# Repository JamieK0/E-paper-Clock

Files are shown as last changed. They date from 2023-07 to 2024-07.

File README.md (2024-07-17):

# Easy on the Eyes E-paper Clock
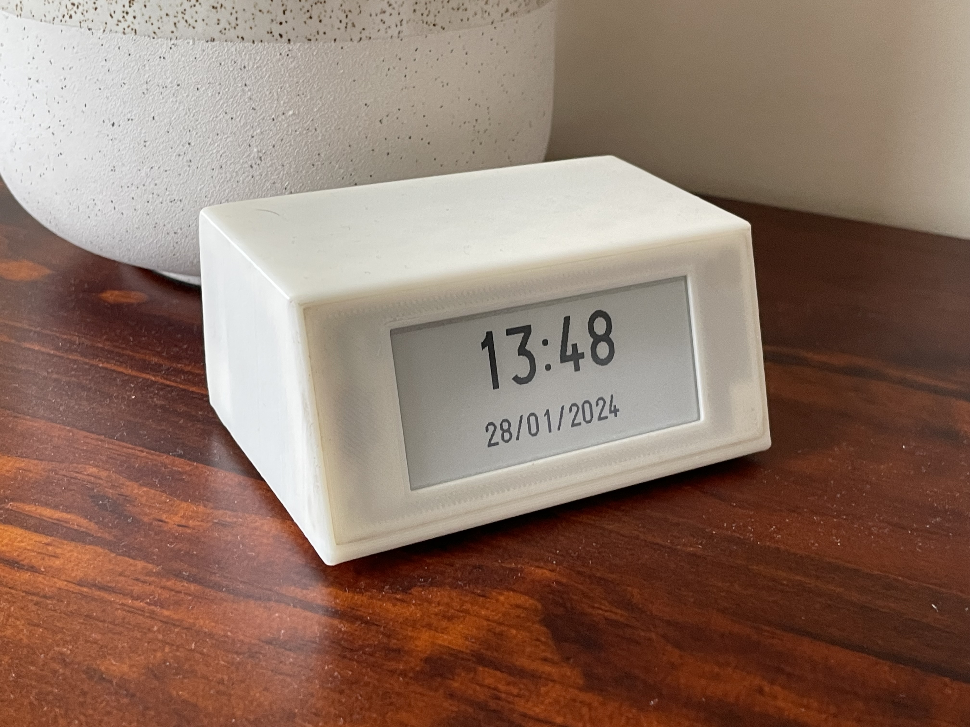
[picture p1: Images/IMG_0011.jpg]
Clock

## Introduction
This project started as a desire to have a modern digital clock that would use the natural light of the room for illumination. This means that the screen is always at a natural brightness, with it looking like paper rather than a traditional screen. By using an E-paper display, blue light is not emitted meaning that the clock does not disrupt your circadian rhythm before bed. It seamlessly updates every minute, and on the hour the screen does a full refresh.

Another useful function of the clock is that it uses a supercapacitor to ensure the time is kept even when it is unplugged for extended periods of time. This means the time does not have to be set again after blackouts like most other clocks. 

## Build Guide
### **Assumed Knowledge**
- Soldering 
- Arduino IDE 
- 3D printing

### **Bill of Materials**
- 1x [Arduino Nano or compatible Nano board](https://core-electronics.com.au/nano-v3-0-board.html)
- 1x [Waveshare 2.9inch E-Paper Module for Raspberry Pi Pico](https://core-electronics.com.au/waveshare-2-9inch-e-paper-module-for-raspberry-pi-pico-296x128-black-white.html) 
- 1x [Makerverse Real Time Clock (RTC) with Supercapacitor Backup RV-3028](https://core-electronics.com.au/catalog/product/view/sku/CE07922)
- 4x [Push Button 12mm x 12mm](https://core-electronics.com.au/tactile-switch-buttons-12mm-square-6mm-tall-x-10-pack.html)
- 1x [Micro USB Cable](https://core-electronics.com.au/usb-cable-type-a-to-micro-b-1m.html)
- 6x M3 4mm length (OD 4.5mm) heated inserts
- 3x M3 16mm hex socket grubscrews
- Jumper wires
- Wires 
- Solder
- White PLA 3D printer filament\

### **Tools**
- 3D printer 
- Soldering Iron
- Hot glue gun

### **Wiring Table**

| Arduino | E-paper Display | RTC unit | Buttons |
| --- | --- | --- | --- |
| 5V | VSYS | | |
| 3V3 | | Vcc | |
| GND | GND | GND | All buttons bottom right pin |
| A4 | | SDA | |
| A5 | | SCL | |
| D2 | | INT | |
| D3 | | | Button 1 bottom left pin (Down) |
| D4 | | | Button 2 bottom left pin (Change function from changing hours to changing minutes to exit changing time mode) |
| D5 | | | Button 3 bottom left pin (Turn on changing time mode) |
| D6 | DC | | |
| D7 | BUSY | | |
| D8 | | | Button 4 bottom right pin (Up) |
| D9 | RST | | |
| D10 | CS | | |
| D11 | DIN | | |
| D13 | CLK | CLK | |

### **Schematic**
Schematic
### **Assembly Instructions**
1. Connect the jumper wires from the Arduino’s male headers to the female headers on the E-paper module according to the schematic diagram or wiring table below. Some connections may need to be soldered, like the D13-CLK-CLK connection, since multiple devices are connecting to the same pin on the Arduino. The buttons all have to be soldered as well. Keep at least 8cm on each wire connected to the button so that there is enough slack for the buttons to be placed at the back of the case.
2. Optionally hot glue the jumper wire connections so that they cannot lose contact over time. For a more permanent setup, all the connections can be soldered.
3. Plug the Arduino Nano into your computer and adjust the Arduino sketch.
   	1. Ensure that the ZIP libraries are all installed. They are all on the Github repository below under the E-paper_Clock folder. Install them at Sketch → Include Library → Add .ZIP Library. The libraries are Low Power, GxEPD2 and U8g2 for Adafruit GFX.
	2. Ensure that the time and date variables (int year =, int month =, etc) are set to the current date and time.Variables
	3. Uncomment line 59 by removing the ‘//’ from the start. Line 59:
```
//rtc.setTime(sec, minute, hour, day, date, month, year); //USE THIS TO INITALLY SET TIME. Once set it needs to be commented out so that it doesn't get set to this time every restart
```
3.
   	4. Upload the sketch. Set the board to Arduino AVR Boards → Arduino Nano. 
	5. Turn the line above back into a comment by adding the ‘//’ to the start so that it looks like:
```
//rtc.setTime(sec, minute, hour, day, date, month, year); //USE THIS TO INITALLY SET TIME. Once set it needs to be commented out so that it doesn't get set to this time every restart
```
3.
	6. Upload the sketch again. The clock is now programmed.
4. 3D print the 3 case parts. They can be printed individually or all together.
5. The main case might need a brim depending on your printer since the contact area is quite small.

#### Print settings:
- Filament type: PLA
- Nozzle Temperature: 210ºC
- Bed Temperature: 60ºC
- Infill: 15%
- Layer Height: 0.2mm
- Perimeters: 3
- Solid Layers:
- Top: 4
- Bottom: 4
Print
6. Melt the heated inserts into the 6 holes in the 3d print using a soldering iron. [Video demonstration](https://youtu.be/i6GkWjcWj5w?t=235).
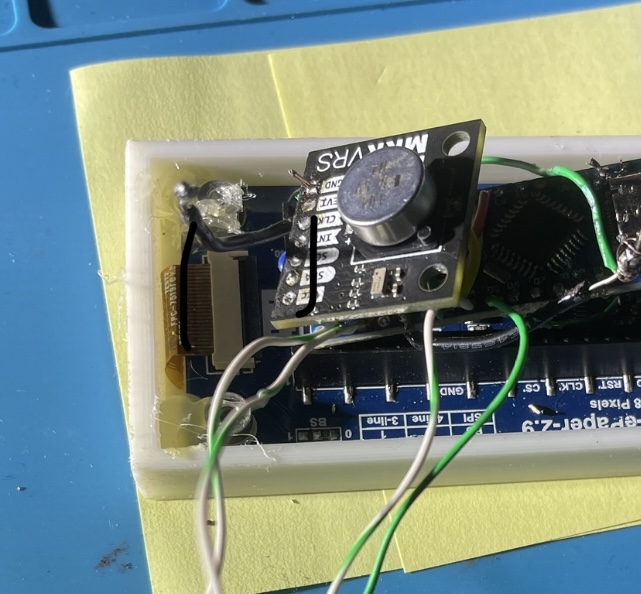
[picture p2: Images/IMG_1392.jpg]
Build
7. Remove the e-paper screen protector and position the screen in the 3d print with the screen opening. Hot glue the corners of the back of the screen to the 3d print.
8. Move all the electronics through the front of the main case and press the front closed. Its friction fit so it might take some force depending on your printer’s dimensional accuracy.
9. Hot glue each button to the back piece in the button holes. Order the buttons so that they make sense when using them to change the time, i.e. the down button is below the up button.
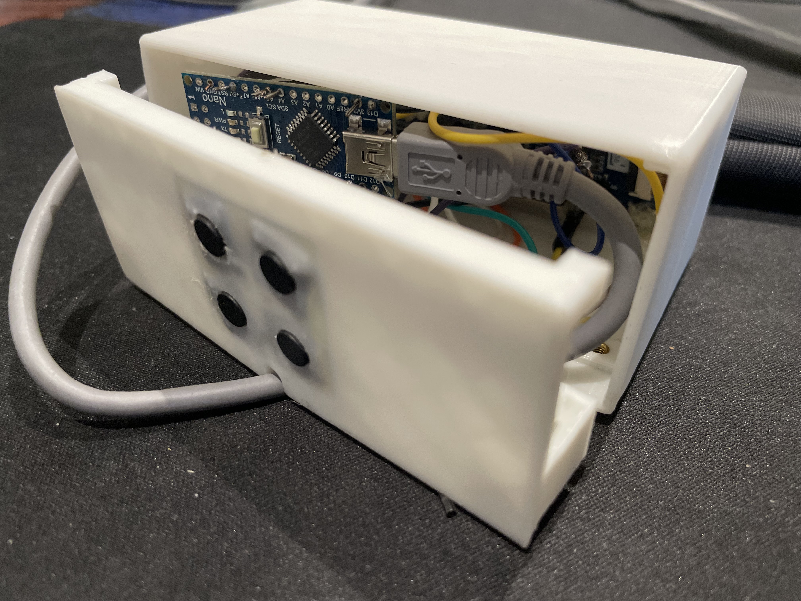
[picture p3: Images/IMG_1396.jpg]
Build2
10. Plug the USB cable into the Arduino and guide the cable through the hole at the bottom of the back piece.
11. Push the back piece into the case of the clock. Once again it’s a friction fit.
12. Screw the 3 grubscrews through the heated inserts at the bottom of the case. This will hold all the pieces of the case together.
13. Plug the Arduino to a USB wall plug or computer port for power.

## How to Adjust the Time
1. Click the ‘Changing time mode button’
2. Use the up and down button to change the hour. There might be a little delay since e-paper screens have a low refresh rate.
3. Click the change function button so that the up and down buttons can be used to adjust the minutes.
4. Click the change function button again to exit change time mode. Once the screen does a full refresh, the new time is saved.

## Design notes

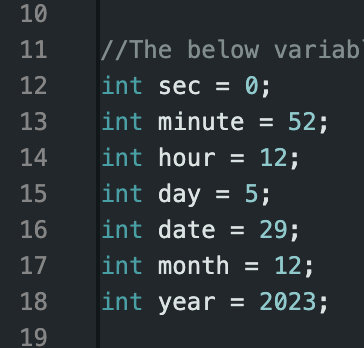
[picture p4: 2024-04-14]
Images/Screenshot 2024-04-13 at 2.12.42 pm.png

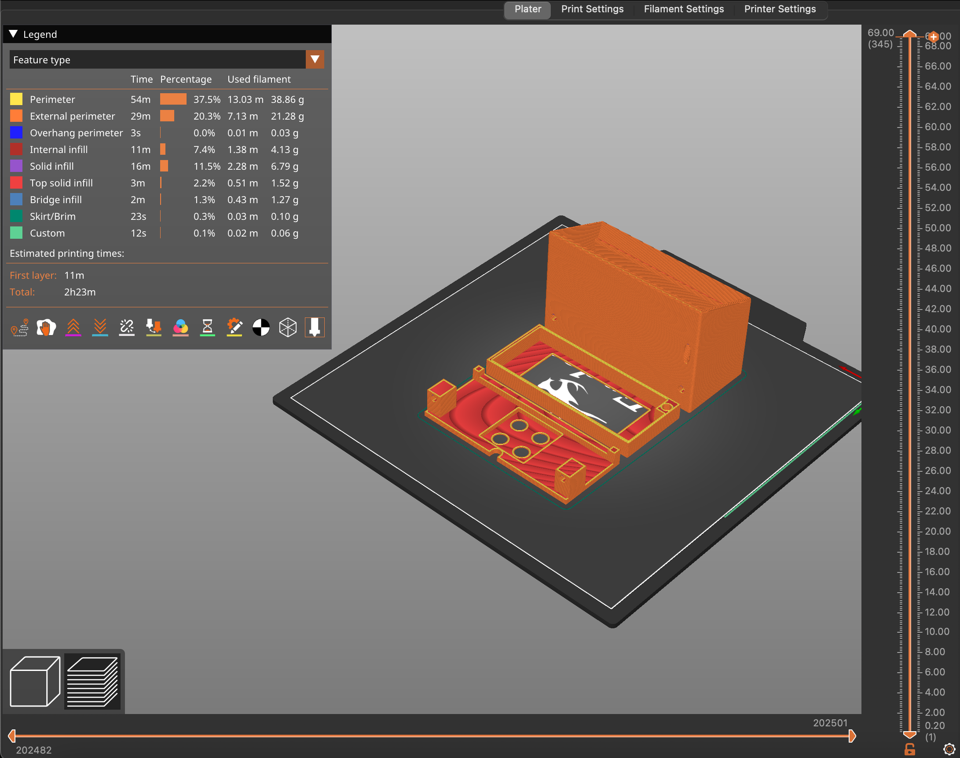
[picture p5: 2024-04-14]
Images/Screenshot 2024-04-13 at 2.23.16 pm.png

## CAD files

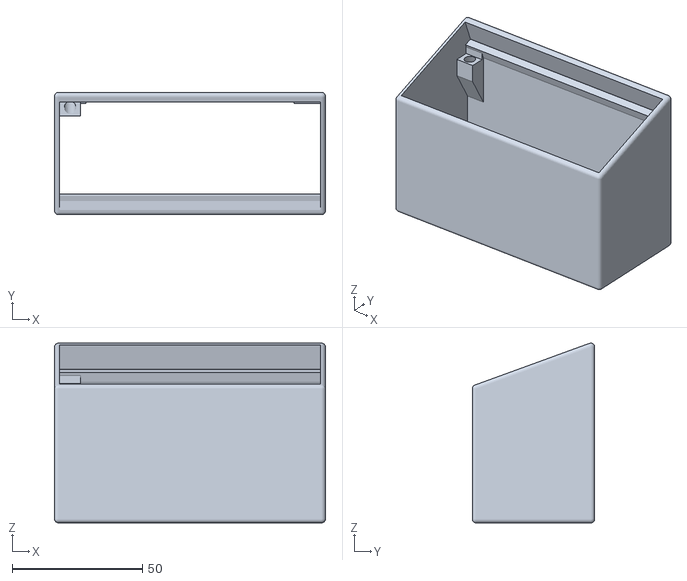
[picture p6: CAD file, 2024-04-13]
3D Models/Case.stl
104.0 x 47.0 x 69.0

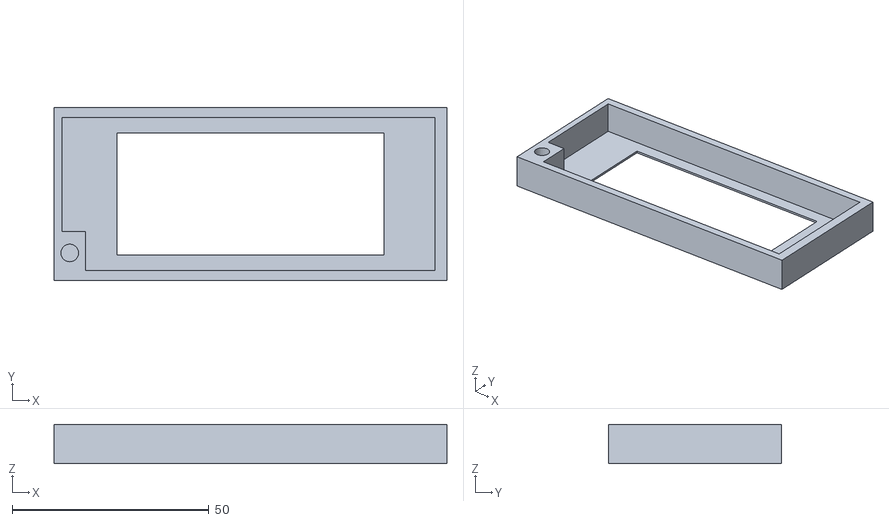
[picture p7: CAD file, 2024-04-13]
3D Models/Front.stl
100.0 x 44.0 x 10.0

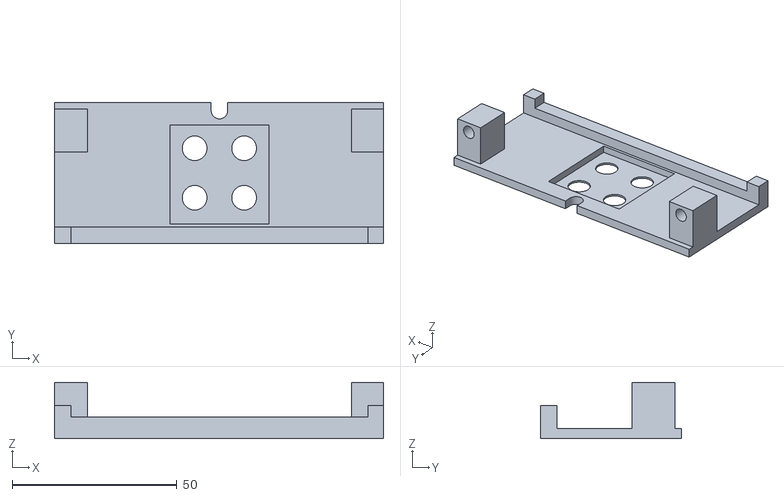
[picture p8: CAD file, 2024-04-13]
3D Models/Back.stl
99.8 x 42.8 x 17.0

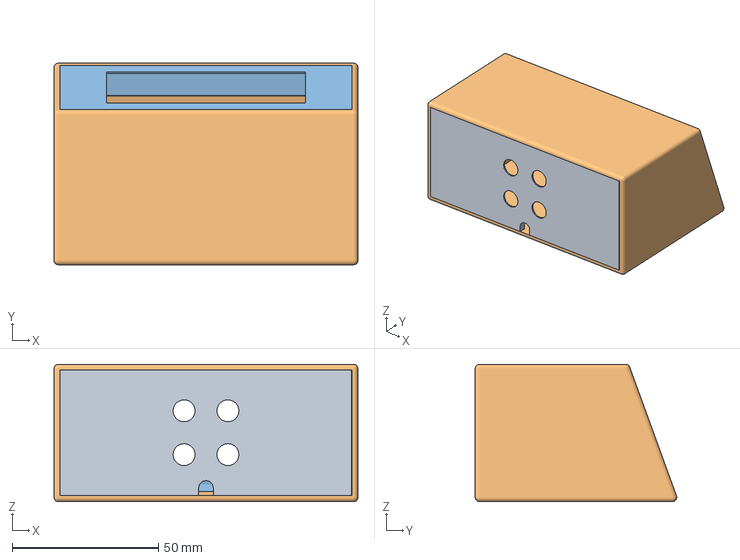
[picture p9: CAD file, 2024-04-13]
3D Models/Combined.3mf
104.0 x 69.0 x 47.0 mm

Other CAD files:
3D Models/Project File Fusion 360.f3d

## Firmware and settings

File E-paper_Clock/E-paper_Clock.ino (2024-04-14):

#include <RV-3028-C7.h>             // RTC Library
#include <LowPower.h>               // Reduces power consumption https://github.com/rocketscream/Low-Power
#include <U8g2_for_Adafruit_GFX.h>  // https://github.com/olikraus/U8g2_for_Adafruit_GFX
#include <GxEPD2_BW.h>              // including both doesn't use more code or ram

// select the display class and display driver class in the following file (new style):
#include "GxEPD2_display_selection.h"

//The below variables control what the date will be set to. Uncomment the line bellow in setup that sets the rtc to the time here. After compiling, the line needs to be commented out again so that the Arduino does not set the time to this time every time it loses power
int sec = 0;
int minute = 52;
int hour = 12;
int day = 5;
int date = 29;
int month = 12;
int year = 2023;

U8G2_FOR_ADAFRUIT_GFX u8g2Fonts;  // font constructor
RV3028 rtc;                       // create the RTC object

const uint8_t wakeUpPin(2);  // connect Arduino pin D2 to RTC's SQW pin. Wakes up the Arduino each minute from sleep mode.

const uint8_t changeFunc(4);  // Button to change function from changing hours to changing minutes to exit changing time mode
const uint8_t changeOn(5);    // Button to turn on changing time mode, this button causes the interrupt. Do not change this pin to any other pin unless the PCINT paramaters are also changed below.
const uint8_t up(8);          // Button to increase time
const uint8_t down(3);        // Button to decrease time

volatile int changeTime = 0; //Integer that gets changed when the interrupt occurs
int changeFuncState = 0;  //Function button set to 0 initally

void setup() {
  Serial.begin(115200);
  Wire.begin();
  if (rtc.begin() == false) {
    Serial.println("Something went wrong, check wiring");
    while (1)
      return;
  } else
    Serial.println("RTC online!");
  Serial.println();

  u8g2Fonts.begin(display);  // connect the u8g2 display

  // configures interupt pin
  pinMode(wakeUpPin, INPUT_PULLUP);

  // time adjustment buttons with pullup resistor
  pinMode(changeOn, INPUT_PULLUP);
  pinMode(changeFunc, INPUT_PULLUP);
  pinMode(up, INPUT_PULLUP);
  pinMode(down, INPUT_PULLUP);

  // allows for the change time buttons to interput the loop
  PCICR |= B00000100;                                      //turns on PCINT for pins in group D
  PCMSK2 |= B00100000;                                     //Pin D5 will cause interupt
  rtc.enableTrickleCharge(TCR_3K);                         //series resistor 3kOhm
  //rtc.setTime(sec, minute, hour, day, date, month, year);  //USE THIS TO INITALLY SET TIME. Once set it needs to be commented out so that it doesn't get set to this time every restart
  displayDate();
}

ISR(PCINT2_vect) {
  changeTime = 1;
}


// Displays the date in the bottom half of the screen
// and does a complete screen refresh
void displayDate() {
  Serial.println("DISPLAY DATE = start");

  display.init();

  display.setRotation(3);  //0 is 'portrait'

  u8g2Fonts.setForegroundColor(GxEPD_BLACK);
  u8g2Fonts.setBackgroundColor(GxEPD_WHITE);
  u8g2Fonts.setFont(u8g2_font_logisoso20_tr);

  rtc.updateTime();

  String dateString = rtc.stringDate();  //rtc to output current date
  Serial.println(rtc.stringDate());

  uint16_t x = 73;
  uint16_t y = 110;  //bottom
  // covers bottom half
  display.setFullWindow();
  display.firstPage();
  do  // update the whole screen
  {
    u8g2Fonts.setCursor(x, y);
    u8g2Fonts.print(rtc.stringDate());
  } while (display.nextPage());
  display.hibernate();
  Serial.println("DISPLAY DATE = finished");
}

// Displays the time in the top half of the screen, as a partial refresh
void displayTime() {
  Serial.println("DISPLAY TIME = start");
  rtc.updateTime();

  u8g2Fonts.setForegroundColor(GxEPD_BLACK);
  u8g2Fonts.setBackgroundColor(GxEPD_WHITE);
  // Only numbers and symbols to save space.https://github.com/olikraus/u8g2/wiki/fntlist99#50-pixel-height
  u8g2Fonts.setFont(u8g2_font_logisoso50_tn);

  uint16_t x = 70;
  uint16_t y = 62;  //top half, depends on font

  display.setPartialWindow(0, 0, display.width(), display.height() / 2);
  display.firstPage();
  do  // Update the upper part of the screen
  {
    u8g2Fonts.setCursor(x, y);
    if (rtc.getHours() < 10) {
      u8g2Fonts.print(0);
      u8g2Fonts.print(rtc.getHours());
    } else {
      u8g2Fonts.print(rtc.getHours());
    }
    u8g2Fonts.print(":");
    if (rtc.getMinutes() < 10) {
      u8g2Fonts.print(0);
      u8g2Fonts.print(rtc.getMinutes());
    } else {
      u8g2Fonts.print(rtc.getMinutes());
    }
  } while (display.nextPage());
  display.hibernate();
  Serial.println("DISPLAY TIME = finish");
}


void loop() {
  Serial.println("LOOP = start");

  if (rtc.getMinutes() == 0) {
    // Refresh the display completely on the hour
    displayDate();
  }

  displayTime();

  Serial.println("LOOP = before sleep");

  delay(500);

  rtc.enablePeriodicUpdateInterrupt(0, 0);

  // Allow wake up pin to trigger on interrupt low.
  attachInterrupt(digitalPinToInterrupt(2), alarmIsr, FALLING);

  Serial.println("VOID LOOP = powering down");

  delay(500);  // if this isn't here the arduino seems to fall asleep before finishing the last line

  // Power down
  LowPower.powerDown(SLEEP_FOREVER, ADC_OFF, BOD_OFF);

  // Wakes up here!
  Serial.println("VOID LOOP = woke up");

  // Disable external pin interrupt on wake up pin.
  detachInterrupt(digitalPinToInterrupt(2));

// Change time code
  while (changeTime == 1) {
    Serial.println("changetime");
    byte upState = digitalRead(up);
    byte downState = digitalRead(down);
    digitalRead(changeFunc);


    if (digitalRead(changeFunc) == LOW) {
      changeFuncState = changeFuncState + 1;
      Serial.println(changeFuncState);
      delay(250);
    }

    if (changeFuncState == 0) {  // Changes the hours. Runs when changeFuncState == 0, therefore runs right after the ISR and is the default mode.
      if (upState == LOW) {
        delay(250);
        Serial.println("hr, up");
        rtc.setHours(rtc.getHours() + 1);
        displayTime();
      } else if (downState == LOW) {
        delay(250);
        Serial.println("hr, down");
        rtc.setHours(rtc.getHours() - 1);
        displayTime();
      }
    }

    else if (changeFuncState == 1) {  // Changes the minutes
      if (upState == LOW) {
        delay(250);
        Serial.println("min, up");
        rtc.setMinutes(rtc.getMinutes() + 1);
        displayTime();
      } else if (downState == LOW) {
        delay(250);
        Serial.println("min, down");
        rtc.setMinutes(rtc.getMinutes() - 1);
        displayTime();
      }

    } else if (changeFuncState == 2) {  //Turns off change time function of the clock
      changeFuncState = 0;
      changeTime = LOW;
      displayDate();  //Fully refreshes the display
    }
  }
}



void alarmIsr() {
}

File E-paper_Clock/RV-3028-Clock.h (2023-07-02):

/******************************************************************************
RV-3028-C7.h
RV-3028-C7 Arduino Library
Constantin Koch
July 25, 2019
https://github.com/constiko/RV-3028_C7-Arduino_Library

Resources:
Uses Wire.h for I2C operation

Development environment specifics:
Arduino IDE 1.8.9

This code is released under the [MIT License](http://opensource.org/licenses/MIT).
Please review the LICENSE.md file included with this example. If you have any questions
or concerns with licensing, please contact constantinkoch@outlook.com.
Distributed as-is; no warranty is given.
******************************************************************************/

#pragma once

#if (ARDUINO >= 100)
#include "Arduino.h"
#else
#include "WProgram.h"
#endif

#include <Wire.h>



//The 7-bit I2C ADDRESS of the RV3028
#define RV3028_ADDR						(uint8_t)0x52


//REGISTERS
//Clock registers
#define RV3028_SECONDS      			0x00
#define RV3028_MINUTES      			0x01
#define RV3028_HOURS        			0x02
//Calendar registers
#define RV3028_WEEKDAY					0x03
#define RV3028_DATE         			0x04
#define RV3028_MONTHS        			0x05
#define RV3028_YEARS        			0x06

//Alarm registers
#define RV3028_MINUTES_ALM     			0x07
#define RV3028_HOURS_ALM       			0x08
#define RV3028_DATE_ALM        			0x09

//Periodic Countdown Timer registers
#define RV3028_TIMERVAL_0				0x0A
#define RV3028_TIMERVAL_1				0x0B
#define RV3028_TIMERSTAT_0				0x0C
#define RV3028_TIMERSTAT_1				0x0D

//Configuration registers
#define RV3028_STATUS					0x0E
#define RV3028_CTRL1					0x0F
#define RV3028_CTRL2					0x10
#define RV3028_GPBITS					0x11
#define RV3028_INT_MASK					0x12

//Eventcontrol/Timestamp registers
#define RV3028_EVENTCTRL				0x13
#define RV3028_COUNT_TS					0x14
#define RV3028_SECONDS_TS				0x15
#define RV3028_MINUTES_TS				0x16
#define RV3028_HOURS_TS					0x17
#define RV3028_DATE_TS					0x18
#define RV3028_MONTH_TS					0x19
#define RV3028_YEAR_TS					0x1A

//Unix Time registers
#define RV3028_UNIX_TIME0				0x1B
#define RV3028_UNIX_TIME1				0x1C
#define RV3028_UNIX_TIME2				0x1D
#define RV3028_UNIX_TIME3				0x1E

//RAM registers
#define RV3028_USER_RAM1				0x1F
#define RV3028_USER_RAM2				0x20

//Password registers
#define RV3028_PASSWORD0				0x21
#define RV3028_PASSWORD1				0x22
#define RV3028_PASSWORD2				0x23
#define RV3028_PASSWORD3				0x24

//EEPROM Memory Control registers
#define RV3028_EEPROM_ADDR				0x25
#define RV3028_EEPROM_DATA				0x26
#define RV3028_EEPROM_CMD				0x27

//ID register
#define RV3028_ID						0x28

//EEPROM Registers
#define EEPROM_Clkout_Register			0x35
#define RV3028_EEOffset_8_1				0x36	//bits 8 to 1 of EEOffset. Bit 0 is bit 7 of register 0x37 
#define EEPROM_Backup_Register			0x37


//BITS IN IMPORTANT REGISTERS

//Bits in Status Register
#define STATUS_EEBUSY	7
#define STATUS_CLKF		6
#define STATUS_BSF		5
#define STATUS_UF		4
#define STATUS_TF		3
#define STATUS_AF		2
#define STATUS_EVF		1
#define STATUS_PORF		0

//Bits in Control1 Register
#define CTRL1_TRPT		7
#define CTRL1_WADA		5//Bit 6 not implemented
#define CTRL1_USEL		4
#define CTRL1_EERD		3
#define CTRL1_TE		2
#define	CTRL1_TD1		1
#define CTRL1_TD0		0

//Bits in Control2 Register
#define CTRL2_TSE		7
#define CTRL2_CLKIE		6
#define CTRL2_UIE		5
#define CTRL2_TIE		4
#define CTRL2_AIE		3
#define CTRL2_EIE		2
#define CTRL2_12_24		1
#define CTRL2_RESET		0

//Bits in Hours register
#define HOURS_AM_PM			5

//Bits in Alarm registers
#define MINUTESALM_AE_M		7
#define HOURSALM_AE_H		7
#define DATE_AE_WD			7

//Commands for EEPROM Command Register (0x27)
#define EEPROMCMD_First					0x00
#define EEPROMCMD_Update				0x11
#define EEPROMCMD_Refresh				0x12
#define EEPROMCMD_WriteSingle			0x21
#define EEPROMCMD_ReadSingle			0x22

//Bits in EEPROM Backup Register
#define EEPROMBackup_TCE_BIT			5				//Trickle Charge Enable Bit
#define EEPROMBackup_FEDE_BIT			4				//Fast Edge Detection Enable Bit (for Backup Switchover Mode)
#define EEPROMBackup_BSM_SHIFT			2				//Backup Switchover Mode shift
#define EEPROMBackup_TCR_SHIFT			0				//Trickle Charge Resistor shift

#define EEPROMBackup_BSM_CLEAR			0b11110011		//Backup Switchover Mode clear
#define EEPROMBackup_TCR_CLEAR			0b11111100		//Trickle Charge Resistor clear
#define	TCR_3K							0b00			//Trickle Charge Resistor 3kOhm
#define	TCR_5K							0b01			//Trickle Charge Resistor 5kOhm
#define	TCR_9K							0b10			//Trickle Charge Resistor 9kOhm
#define	TCR_15K							0b11			//Trickle Charge Resistor 15kOhm


// Clock output register (0x35)
#define EEPROMClkout_CLKOE_BIT			7				//1 = CLKOUT pin is enabled. – Default value on delivery 
#define EEPROMClkout_CLKSY_BIT			6
// Bits 5 and 4 not implemented
#define EEPROMClkout_PORIE				  3				//0 = No interrupt, or canceled, signal on INT pin at POR. – Default value on delivery
																		//1 = An interrupt signal on INT pin at POR. Retained until the PORF flag is cleared to 0 (no automatic cancellation). 
#define EEPROMClkout_FREQ_SHIFT			0				//frequency shift
#define FD_CLKOUT_32k					  0b000			  //32.768 kHz – Default value on delivery 
#define FD_CLKOUT_8192					0b001 			//8192 Hz 
#define FD_CLKOUT_1024					0b010			  //1024 Hz
#define FD_CLKOUT_64					  0b011 		  //64 Hz 
#define FD_CLKOUT_32					  0b100			  //32 Hz
#define FD_CLKOUT_1						  0b101 		 	//1 Hz 
#define FD_CLKOUT_TIMER					0b110			  //Predefined periodic countdown timer interrupt 
#define FD_CLKOUT_LOW					  0b111 			//CLKOUT = LOW 


#define IMT_MASK_CEIE					3				//Clock output when Event Interrupt bit. 
#define IMT_MASK_CAIE					2				//Clock output when Alarm Interrupt bit.
#define IMT_MASK_CTIE					1				//Clock output when Periodic Countdown Timer Interrupt bit.
#define IMT_MASK_CUIE					0				//Clock output when Periodic Time Update Interrupt bit.


#define TIME_ARRAY_LENGTH 7 // Total number of writable values in device

enum time_order {
	TIME_SECONDS,    // 0
	TIME_MINUTES,    // 1
	TIME_HOURS,      // 2
	TIME_WEEKDAY,    // 3
	TIME_DATE,       // 4
	TIME_MONTH,      // 5
	TIME_YEAR,       // 6
};
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

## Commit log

2023-09-28 my reduced font pack not working
    [E-paper_Clock.ino]
2023-09-28 Working Date and Time
    Working Date and Time
    No adjustment buttons or alarms yet
2023-12-27 Fix date not showing
    Seems like broken string
    [E-paper_Clock.ino]
2023-12-28 with no lib isr not working
    [E-paper_Clock.ino]
2023-12-29 Change time functions and buttons work
    Doesnt change the time yet but the buttons work
2024-04-13 Add 3d files
    [Back.stl, Case.stl, Combined.3mf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]
2025-02-18 Arduino Code
